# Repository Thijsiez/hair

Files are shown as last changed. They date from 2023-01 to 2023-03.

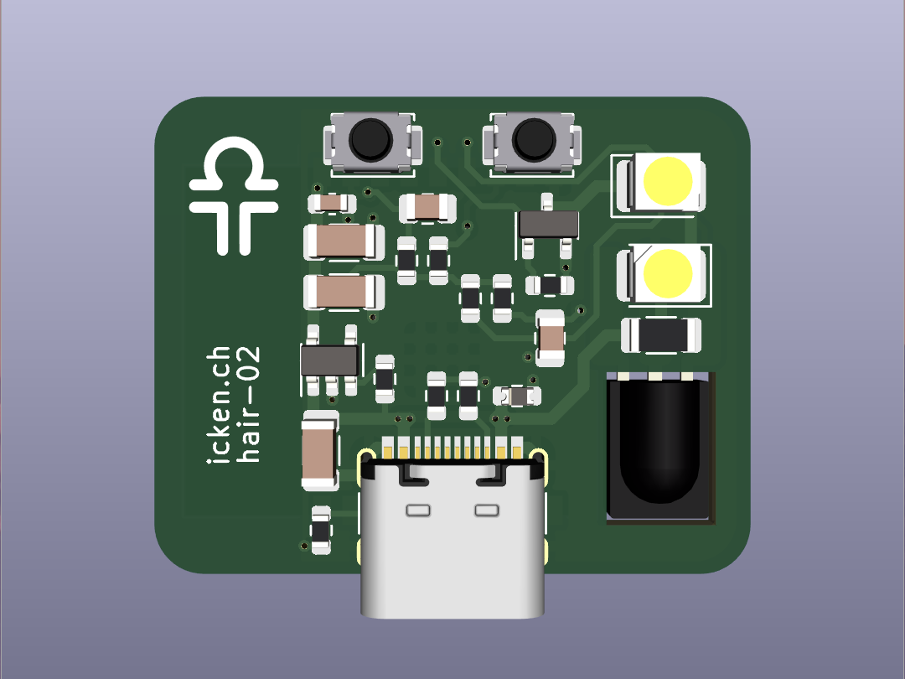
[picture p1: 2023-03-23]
hair-02/images/KiCad 3D Viewer Front.png

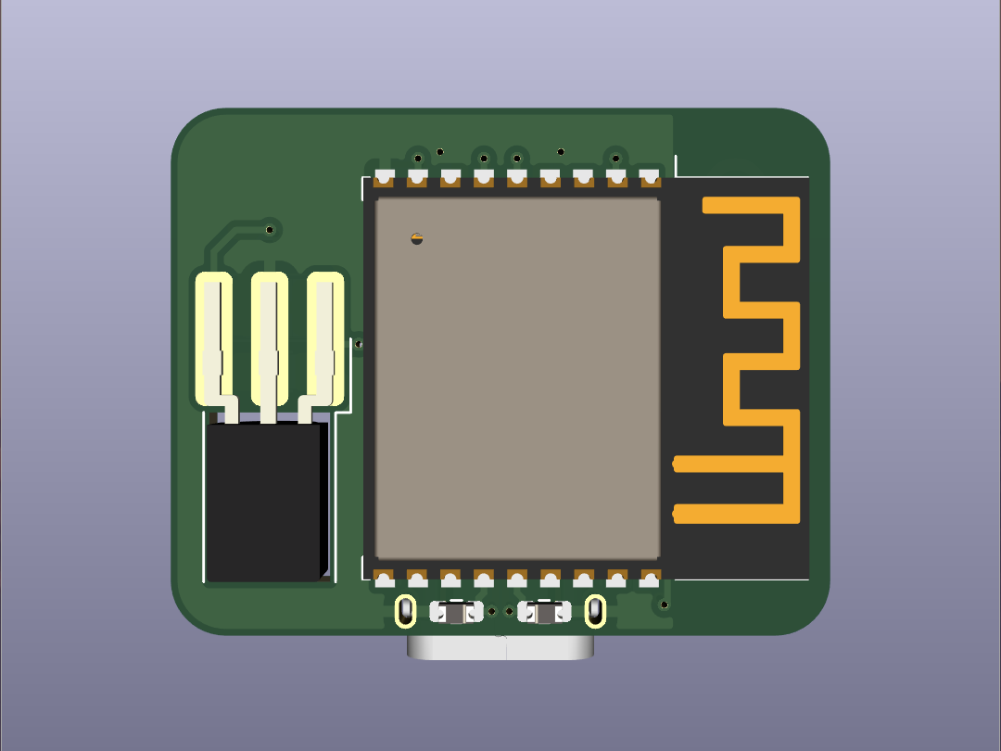
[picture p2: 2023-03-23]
hair-02/images/KiCad 3D Viewer Back.png

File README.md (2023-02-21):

# hair - Home Assistant IR blaster
The joke is that I'm bald :)

## :construction: WIP :construction:
This repo is currently a work-in-progress. I will add more information and documentation later.  
As long as this message is here, I'm open to suggestions but please do not assume anything is done or will work without issues.

## Versions
- [01](./hair-01) is a flawed prototype **DO NOT BUILD OR REFERENCE**
- [02](./hair-02) **WIP**

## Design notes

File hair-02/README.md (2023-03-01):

# hair-02

The goal for 02 is to not need a USB-to-Serial interface chip like 01, lowering the total BOM cost. Another benefit of using the newer ESP32-C3 SoC, compared to the ESP8266, is that it uses the open source RISC-V instruction set.

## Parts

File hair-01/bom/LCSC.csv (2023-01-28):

LCSC Part Number | Manufacture Part Number | Manufacturer | Package | Description | Order Qty.
C13585 | CL31A106KBHNNNE | Samsung Electro-Mechanics | 1206 | 50V 10uF X5R ±10% 1206 Multilayer Ceramic Capacitors MLCC - SMD/SMT ROHS | 25
C14663 | CC0603KRX7R9BB104 | YAGEO | 0603 | 50V 100nF X7R ±10% 0603 Multilayer Ceramic Capacitors MLCC - SMD/SMT ROHS | 10
C316054 | 0603ESDA-05N | BORN | 0603 | 50V 5V Bi-Directional 0603 ESD Protection Devices ROHS | 15
C524055 | HIR67-21C/L289/TR8 | Everlight Elec | SMD3528 | SMD3528 Infrared (IR) LEDs ROHS | 10
C165948 | TYPE-C-31-M-12 | Korean Hroparts Elec | SMD | 5A 1 16 Female Type-C SMD USB Connectors ROHS | 5
C2150 | SS8050 | Jiangsu Changjing Electronics Technology Co., Ltd. | SOT-23-3 | 100nA 25V 300mW 200@100mA,1V 1.5A 100MHz 500mV@800mA,80mA NPN +150℃@(Tj) SOT-23-3 Bipolar Transistors - BJT ROHS | 10
C414015 | 2N7002K | MDD（Microdiode Electronics） | SOT-23 | 60V 500mA 900mΩ@10V,500mA 300mW 1.6V@250uA 1.5pF@30V N Channel 23.8pF@30V 930pC@10V +150℃@(Tj) SOT-23 MOSFETs ROHS | 5
C25804 | 0603WAF1002T5E | UNI-ROYAL(Uniroyal Elec) | 0603 | 100mW Thick Film Resistors 75V ±100ppm/℃ ±1% -55℃~+155℃ 10kΩ 0603 Chip Resistor - Surface Mount ROHS | 45
C23186 | 0603WAF5101T5E | UNI-ROYAL(Uniroyal Elec) | 0603 | 100mW Thick Film Resistors 75V ±100ppm/℃ ±1% -55℃~+155℃ 5.1kΩ 0603 Chip Resistor - Surface Mount ROHS | 15
C22775 | 0603WAF1000T5E | UNI-ROYAL(Uniroyal Elec) | 0603 | 100mW Thick Film Resistors 75V ±1% ±200ppm/℃ -55℃~+155℃ 100Ω 0603 Chip Resistor - Surface Mount ROHS | 5
C144495 | AC1206FR-0733RL | YAGEO | 1206 | 250mW Thick Film Resistors 200V ±100ppm/℃ ±1% -55℃~+155℃ 33Ω 1206 Chip Resistor - Surface Mount ROHS | 5
C202388 | SKRKAHE020 | ALPSALPINE | SMD | 2.9mm 2mm Round Button 50mA Brick nogging 3.9mm SPST 12V SMD Tactile Switches ROHS | 5
C82891 | ESP-12F(ESP8266MOD) | Ai-Thinker | SMD,16x24mm | -90dBm 16dBm ESP8266 PCB On Board Antenna 2.4GHz SMD,16x24mm WiFi Modules ROHS | 5
C51118 | AP2112K-3.3TRG1 | Diodes Incorporated | SOT-25-5 | 65dB@(100Hz,1kHz) 600mA 400mV@(600mA) Fixed 3.3V~3.3V Positive 1 6V SOT-25-5 Linear Voltage Regulators (LDO) ROHS | 5
C969151 | CP2102N-A02-GQFN24R | SILICON LABS | QFN-24-EP(4x4) | QFN-24-EP(4x4) USB ICs ROHS | 5
C511392 | TSMP58000 | Vishay Intertech | SIP-3P-2.54mm | 1.8m ±45° -25℃~+85℃ 700uA 2.5V~5.5V SIP-3P-2.54mm Infrared remote receiver ROHS | 5

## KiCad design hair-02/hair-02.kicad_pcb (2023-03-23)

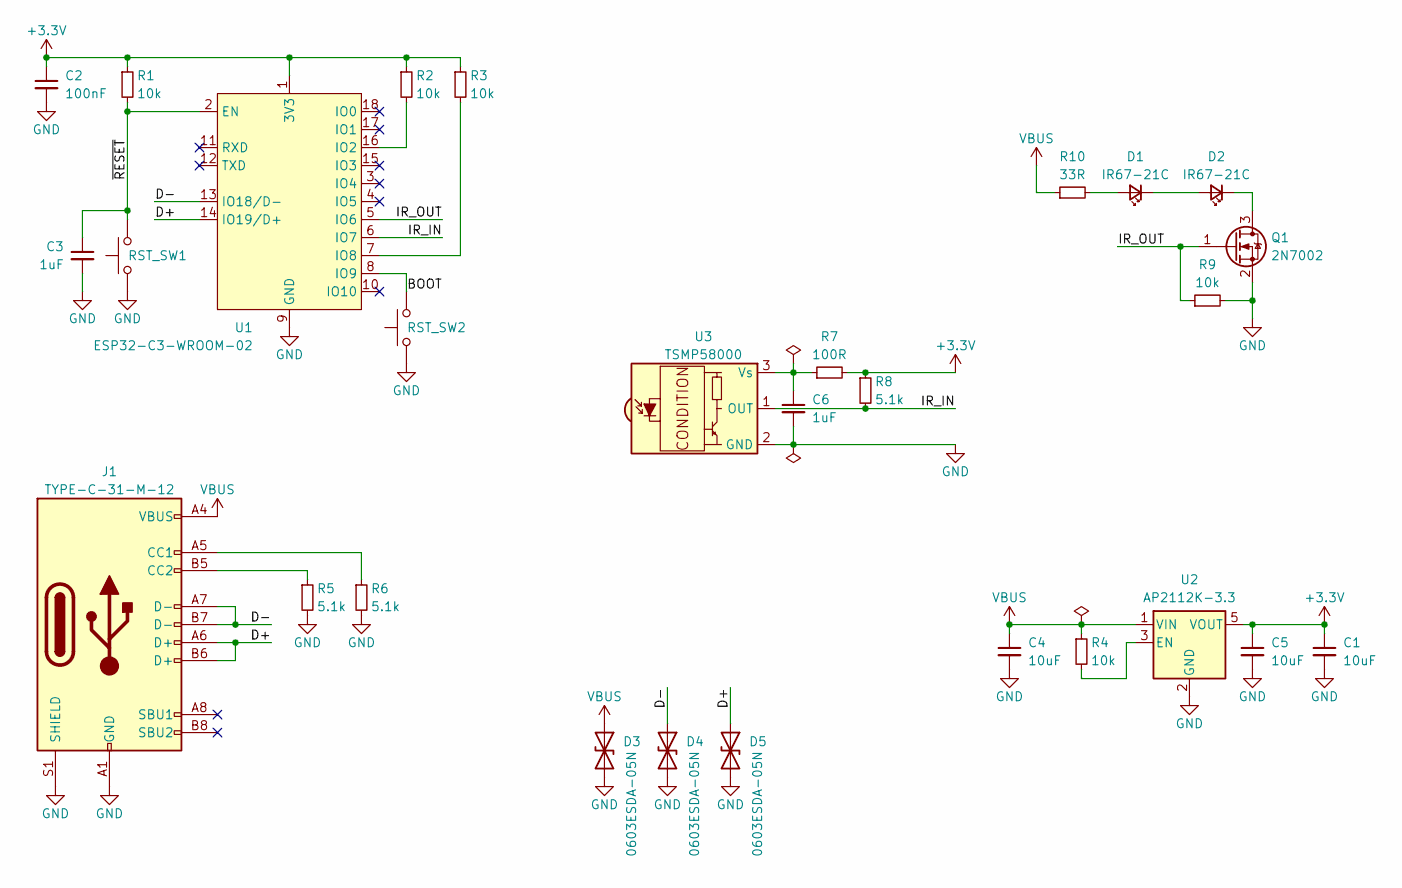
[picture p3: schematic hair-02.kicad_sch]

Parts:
C1, C4, C5: 10uF; C_1206_3216Metric; LCSC C13585
C2: 100nF; C_0603_1608Metric; LCSC C14663
C3, C6: 1uF; C_0805_2012Metric; LCSC C28323
D1, D2: IR67-21C; LED_Everlight_IR67-21C; LCSC C60109
D3, D4, D5: 0603ESDA-05N; D_0603_1608Metric; LCSC C316054
J1: TYPE-C-31-M-12; USB_C_Receptacle_HRO_TYPE-C-31-M-12; LCSC C165948
Q1: 2N7002; SOT-23; LCSC C414015
R1, R2, R3, R4, R9: 10k; R_0603_1608Metric; LCSC C25804
R5, R6, R8: 5.1k; R_0603_1608Metric; LCSC C23186
R7: 100R; R_0603_1608Metric; LCSC C22775
R10: 33R; R_1206_3216Metric; LCSC C144495
RST_SW1, RST_SW2: SKRK; SW_Push_SPST_NO_Alps_SKRK; LCSC C202388
U1: ESP32-C3-WROOM-02; LCSC C2934560
U2: AP2112K-3.3; SOT-23-5; LCSC C51118
U3: TSMP58000; Vishay_MINICAST-3Pin-SMD_ReverseMount; LCSC C511392

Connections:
+3V3: C1.1, C2.1, C5.1, R1.1, R2.1, R3.1, R7.2, R8.1, U1.1 (3V3), U2.5 (VOUT)
/BOOT: RST_SW2.2, U1.8 (IO9)
/D+: D5.1 (A1), J1.A6 (D+), J1.B6 (D+), U1.14 (IO19/D+)
/D-: D4.1 (A1), J1.A7 (D-), J1.B7 (D-), U1.13 (IO18/D-)
/IR_IN: R8.2, U1.6 (IO7), U3.1 (OUT)
/IR_OUT: Q1.1 (G), R9.1, U1.5 (IO6)
/~RESET: C3.1, R1.2, RST_SW1.2, U1.2 (EN)
GND: C1.2, C2.2, C3.2, C4.2, C5.2, C6.2, D3.2 (A2), D4.2 (A2), D5.2 (A2), J1.A1 (GND), J1.A12 (GND), J1.B1 (GND), J1.B12 (GND), J1.S1 (SHIELD), Q1.2 (S), R5.2, R6.2, R9.2, RST_SW1.1, RST_SW2.1, U1.9 (GND), U1.19 (GND), U2.2 (GND), U3.2 (GND)
unnamed: C6.1, R7.1, U3.3 (Vs)
unnamed: D1.1 (K), D2.2 (A)
unnamed: D1.2 (A), R10.2
unnamed: D2.1 (K), Q1.3 (D)
unnamed: J1.A5 (CC1), R6.1
unnamed: J1.B5 (CC2), R5.1
unnamed: R2.2, U1.16 (IO2)
unnamed: R3.2, U1.7 (IO8)
unnamed: R4.2, U2.3 (EN)
VBUS: C4.1, D3.1 (A1), J1.A4 (VBUS), J1.A9 (VBUS), J1.B4 (VBUS), J1.B9 (VBUS), R4.1, R10.1, U2.1 (VIN)

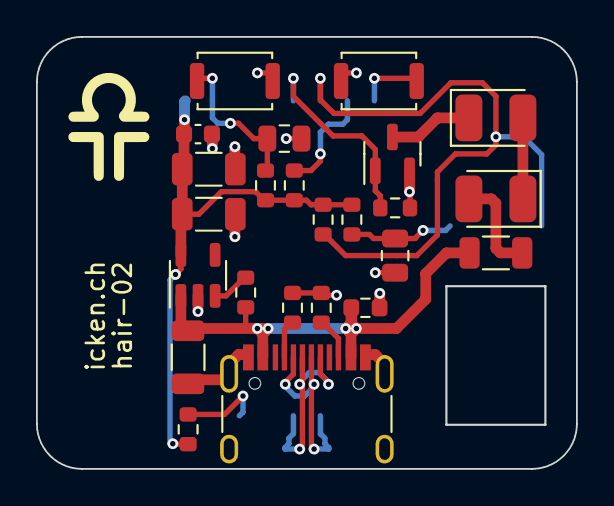
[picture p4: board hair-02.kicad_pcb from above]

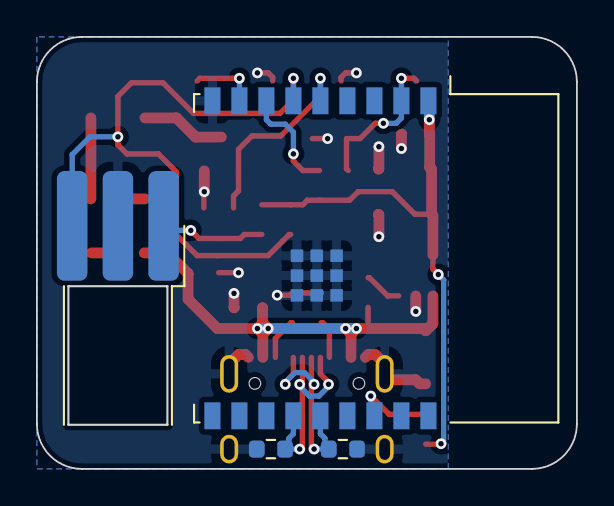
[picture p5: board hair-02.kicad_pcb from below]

Board: 2 copper layers, 30.0 x 24.0 mm, 28 parts (4 on the bottom side), 18 nets.

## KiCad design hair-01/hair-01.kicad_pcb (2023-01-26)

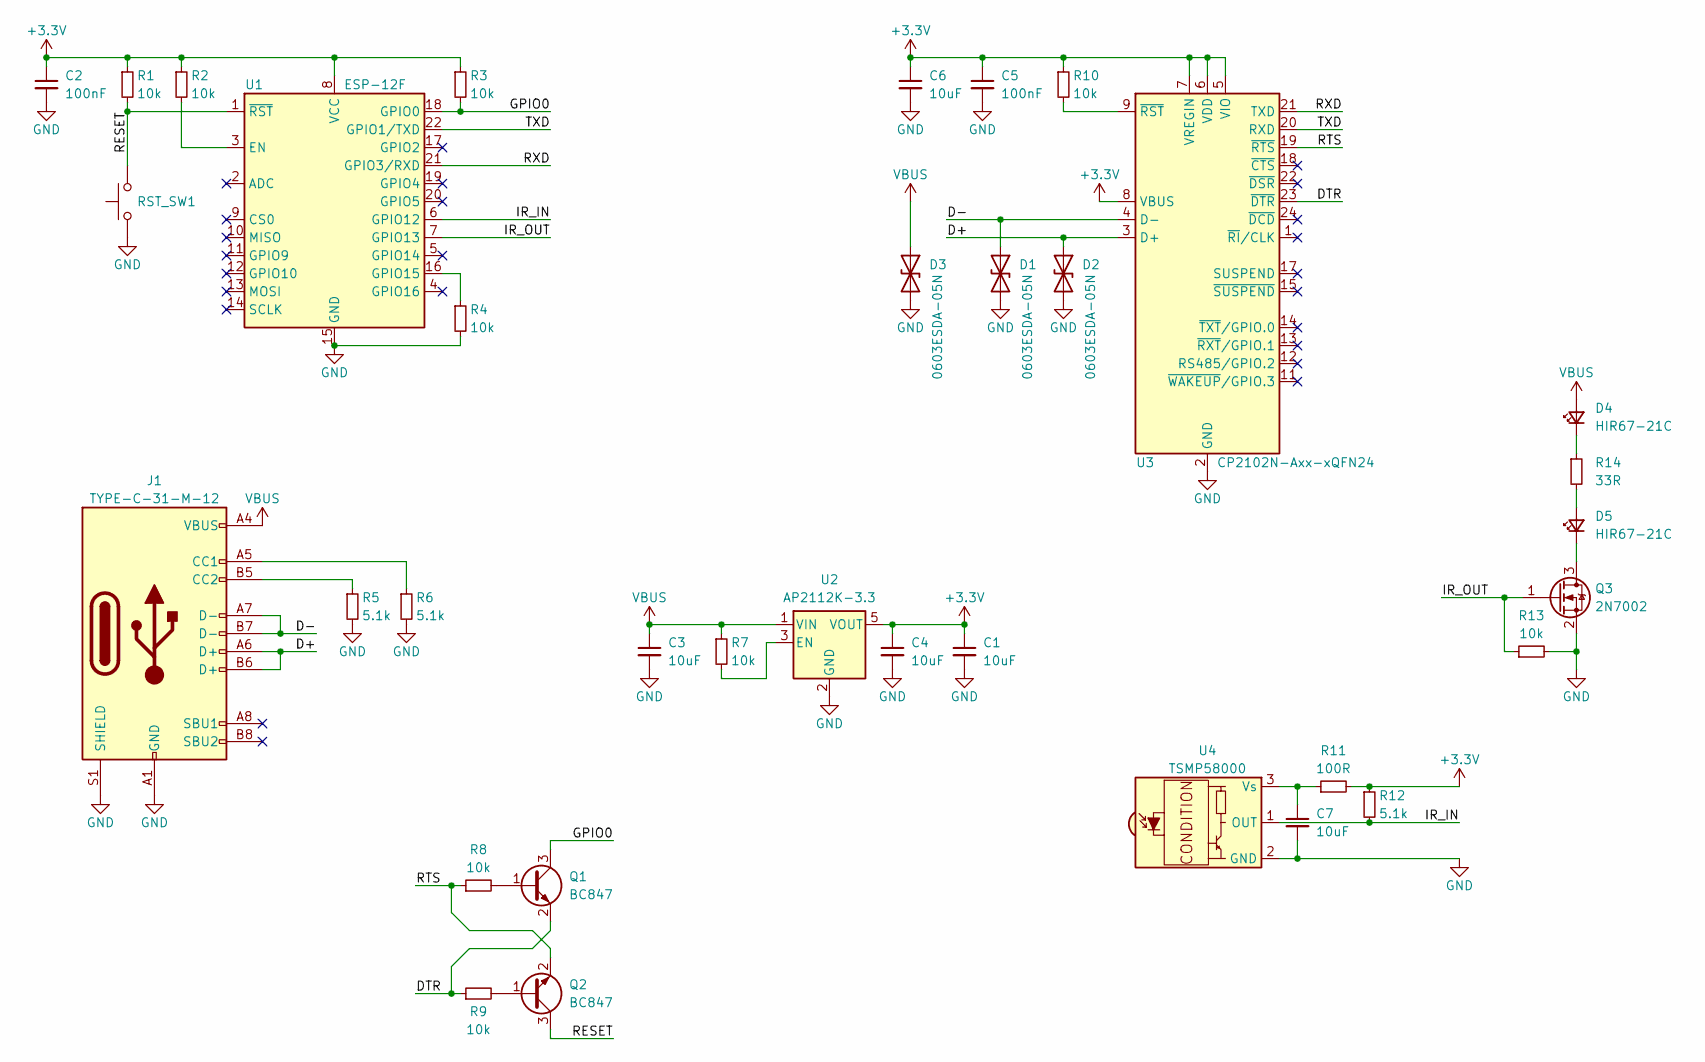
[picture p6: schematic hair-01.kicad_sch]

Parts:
C1, C3, C4, C6, C7: 10uF; C_1206_3216Metric; LCSC C13585
C2, C5: 100nF; C_0603_1608Metric; LCSC C14663
D1, D2, D3: 0603ESDA-05N; D_0603_1608Metric; LCSC C316054
D4, D5: HIR67-21C; LED_Everlight_HIR67-21C; LCSC C524055
J1: TYPE-C-31-M-12; USB_C_Receptacle_HRO_TYPE-C-31-M-12; LCSC C165948
Q1, Q2: BC847; SOT-23; LCSC C2150
Q3: 2N7002; SOT-23; LCSC C414015
R1, R2, R3, R4, R7, R8, R9, R10, R13: 10k; R_0603_1608Metric; LCSC C25804
R5, R6, R12: 5.1k; R_0603_1608Metric; LCSC C23186
R11: 100R; R_0603_1608Metric; LCSC C22775
R14: 33R; R_1206_3216Metric; LCSC C144495
RST_SW1: SW_Push; SW_Push_SPST_NO_Alps_SKRK; LCSC C202388
U1: ESP-12F; ESP-12E; LCSC C82891
U2: AP2112K-3.3; SOT-23-5; LCSC C51118
U3: CP2102N-Axx-xQFN24; QFN-24-1EP_4x4mm_P0.5mm_EP2.6x2.6mm; LCSC C969151
U4: TSMP58000; Vishay_MINICAST-3Pin-SMD; LCSC C511392

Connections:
+3V3: C1.1, C2.1, C4.1, C5.1, C6.1, R1.1, R2.1, R3.1, R10.1, R11.2, R12.1, U1.8 (VCC), U2.5 (VOUT), U3.5 (VIO), U3.6 (VDD), U3.7 (VREGIN), U3.8 (VBUS)
/D+: D2.1 (A1), J1.A6 (D+), J1.B6 (D+), U3.3 (D+)
/D-: D1.1 (A1), J1.A7 (D-), J1.B7 (D-), U3.4 (D-)
/DTR: Q1.2 (E), R9.1, U3.23 (~DTR)
/GPIO0: Q1.3 (C), R3.2, U1.18 (GPIO0)
/IR_IN: R12.2, U1.6 (GPIO12), U4.1 (OUT)
/IR_OUT: Q3.1 (G), R13.1, U1.7 (GPIO13)
/RESET: Q2.3 (C), R1.2, RST_SW1.2, U1.1 (~RST)
/RTS: Q2.2 (E), R8.1, U3.19 (~RTS)
/RXD: U1.21 (GPIO3/RXD), U3.21 (TXD)
/TXD: U1.22 (GPIO1/TXD), U3.20 (RXD)
GND: C1.2, C2.2, C3.2, C4.2, C5.2, C6.2, C7.2, D1.2 (A2), D2.2 (A2), D3.2 (A2), J1.A1 (GND), J1.A12 (GND), J1.B1 (GND), J1.B12 (GND), J1.S1 (SHIELD), Q3.2 (S), R4.2, R5.2, R6.2, R13.2, RST_SW1.1, U1.15 (GND), U2.2 (GND), U3.2 (GND), U3.25 (GND), U4.2 (GND)
unnamed: C7.1, R11.1, U4.3 (Vs)
unnamed: D4.1 (K), R14.1
unnamed: D5.1 (K), Q3.3 (D)
unnamed: D5.2 (A), R14.2
unnamed: J1.A5 (CC1), R6.1
unnamed: J1.B5 (CC2), R5.1
unnamed: Q1.1 (B), R8.2
unnamed: Q2.1 (B), R9.2
unnamed: R2.2, U1.3 (EN)
unnamed: R4.1, U1.16 (GPIO15)
unnamed: R7.2, U2.3 (EN)
unnamed: R10.2, U3.9 (~RST)
VBUS: C3.1, D3.1 (A1), D4.2 (A), J1.A4 (VBUS), J1.A9 (VBUS), J1.B4 (VBUS), J1.B9 (VBUS), R7.1, U2.1 (VIN)

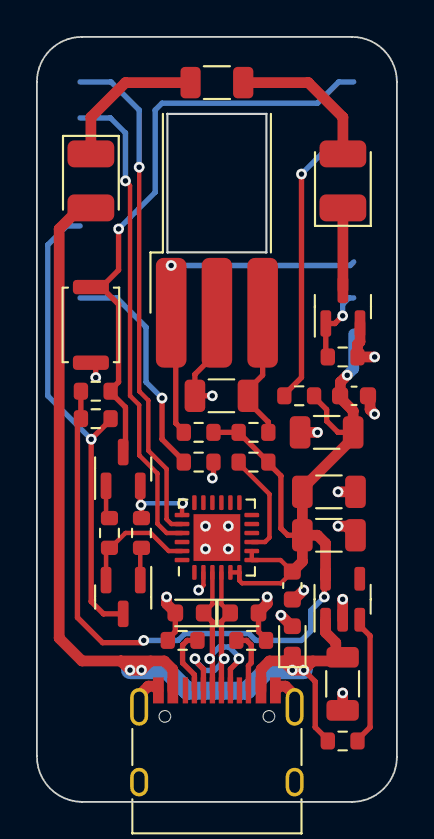
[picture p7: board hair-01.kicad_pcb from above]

Board: 2 copper layers, 20.0 x 42.5 mm, 35 parts (1 on the bottom side), 25 nets.

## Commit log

2023-01-26 hair-01: Add ESP-12F and USB-C receptacle
    [hair-01.kicad_pcb, hair-01.kicad_sch]
2023-01-26 hair-01: Add AP2112
    [hair-01.kicad_sch]
2023-01-26 hair-01: Add reset button and auto-reset
    [hair-01.kicad_sch]
2023-01-26 hair-01: Add CP2102N
    [hair-01.kicad_sch]
2023-01-26 hair-01: Add TSMP58000
    [hair-01.kicad_sch]
2023-01-26 hair-01: Add IR output
    [hair-01.kicad_sch]
2023-01-26 hair-01: Fix small naming mistake
    [hair-01.kicad_sch]
2023-01-26 hair-01: Specify correct footprint for CP2102N
    [hair-01.kicad_sch]
2023-01-26 hair-01: Rotate reset switch
    [hair-01.kicad_sch]
2023-01-26 hair-01: Add footprints and start board layout
    [hair-01.kicad_pcb, hair-01.kicad_sch]
2023-01-26 hair-01: Replace reset button and more routing
    [hair-01.kicad_pcb, hair-01.kicad_sch]
2023-01-26 hair-01: More routing
    [hair-01.kicad_pcb]
2023-01-26 hair-01: Routing done
    [hair-01.kicad_pcb]
2023-01-26 hair-01: Add logo and name to silkscreen
    [hair-01.kicad_pcb]
2023-01-26 hair-01: Add gerbers
    [hair-01-B_Cu.gbl, hair-01-B_Mask.gbs, hair-01-B_Paste.gbp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]
2023-01-26 hair-01: Add interactive BOM
2023-01-26 hair-01: Zip gerbers for JLCPCB ordering
2023-01-28 hair-01: Update README and add example BOM
    [LCSC.csv]
2023-02-21 hair-02: Start designing 02
    [hair-02.kicad_pcb, hair-02.kicad_sch]
2023-02-22 hair-02: Component selection and schematic done
    [hair-02.kicad_sch]
2023-02-22 hair-02: Add ESP32-C3-WROOM-02 footprint
2023-02-22 hair-02: Implement ESP32-C3-WROOM-02 footprint
    [hair-02.kicad_sch]
2023-02-27 hair-02: WIP routing
    [hair-02.kicad_pcb]
2023-02-27 hair-02: WIP more routing
    [hair-02.kicad_pcb, hair-02.kicad_sch]
2023-03-01 hair-02: Routing done
    I'll sleep on it, see if I'm happy with my decisions later
    [hair-02.kicad_pcb, hair-02.kicad_sch]
2023-03-05 hair-02: Add gerbers and interactive BOM
    [hair-02-B_Cu.gbl, hair-02-B_Mask.gbs, hair-02-B_Paste.gbp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]
2023-03-23 hair-02: Add assembly reference images
    [hair-02.kicad_pcb]
